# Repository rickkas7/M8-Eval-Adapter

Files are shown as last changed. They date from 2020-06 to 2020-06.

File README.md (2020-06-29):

# M8-Eval-Adapter

**Hardware design to facilitate prototyping Tracker One designs on the Tracker SoM Evaluation Board**

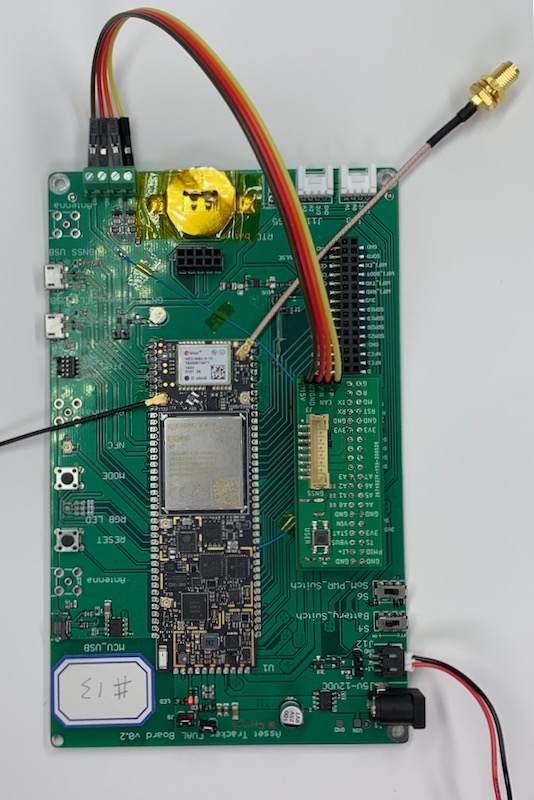
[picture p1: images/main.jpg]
Main Image


This is a simple board you can assemble that makes it easier to prototype designs that will eventually use the Tracker One or Tracker SoM Carrier Board, using the Tracker SoM Evaluation Board.

It fits on the 40 pin expansion connector on the Tracker SoM Evaluation Board and includes features that are on the Tracker One and Tracker Carrier Board:

- B8B-PH connector on the board, the same connector as on the Tracker Carrier Board
- Thermistor (temperature sensor) connected to A0.
- USER button connected to A1
- Blue GNSS LED connected to A2
- CAN connection

The CAN connection is necessary because CAN is not exposed on the 40-pin header. Short wires connect to the screw terminals on the Tracker SoM evaluation board so the CAN will be available on the M8 connector.

**Note:** The Tracker One supports up to 30V on the M8 connector. This adapter board does not have the same power supply as the Tracker One and Tracker Carrier Board. **This adapter board only supports up to 12V using the B8B-PH as a power input!** 

## About the M8 and B8B-PH Connector

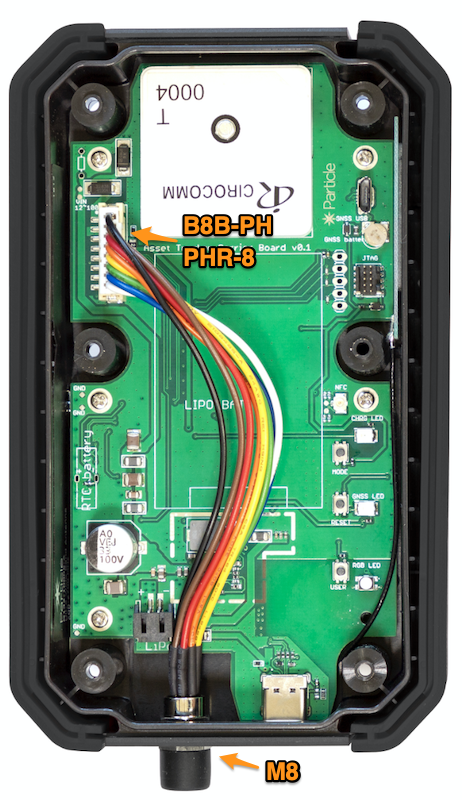
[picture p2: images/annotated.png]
Diagram of inside cable


The Tracker Carrier Board in the Tracker One has a B8B-PH connector on the board.

The Tracker One has a small cable with a PHR-8 connector (fits into the B8B-PH) on one end and an M8 8-pin male IP67 on the other. The M8 end fits into a hole in the case. This is the cable inside the Tracker One:

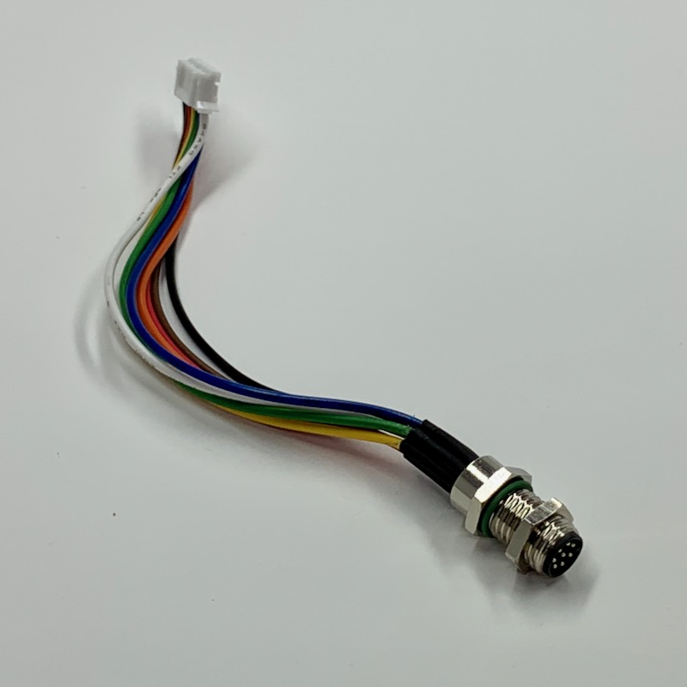
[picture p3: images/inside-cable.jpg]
Cable inside Tracker One


Your Tracker One project will typically use a M8 8-pin female cable. Here's one that has wires on the other end.

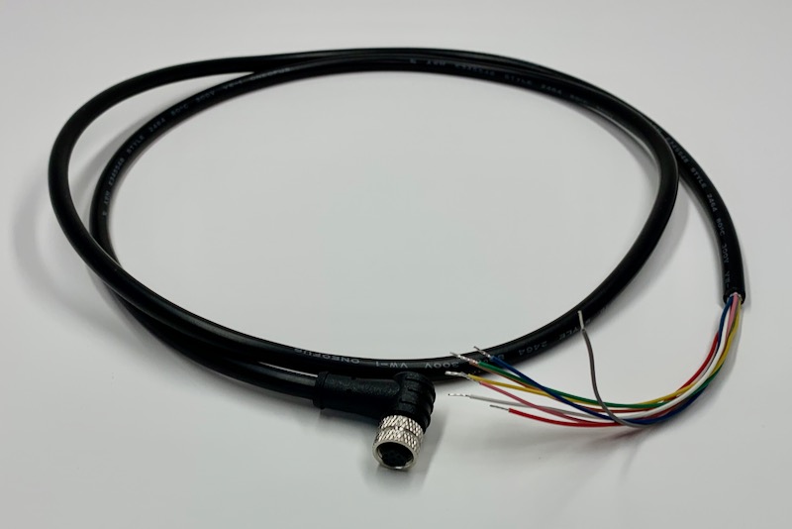
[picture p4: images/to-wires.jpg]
M8 to Wires


You'd typically connect those wires to your custom expansion board using one of several methods:

- Terminate with pins in a PHR-8 to mate with a B8B-PH on your expansion board
- Terminate with screw terminals on your board
- Terminate by soldering the wires to your board

For prototyping, you can just skip the M8 cable and use PHR-8 to wires, or a PHR-8 to PHR-8 cable, as in this example:

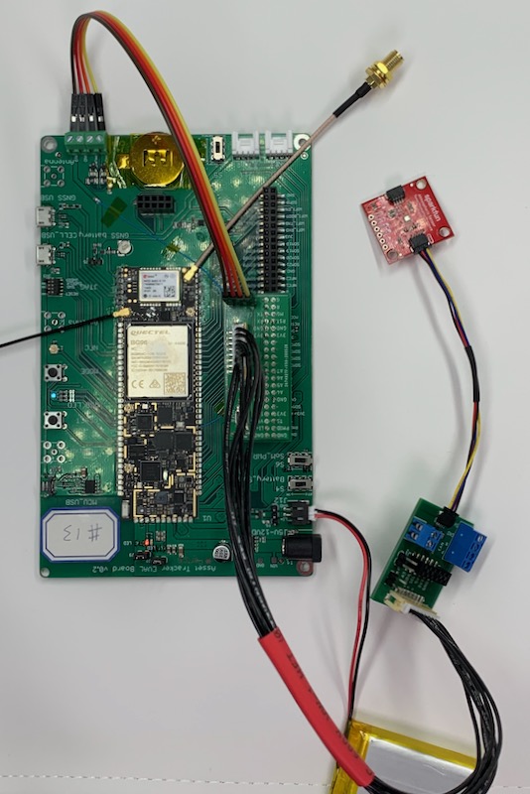
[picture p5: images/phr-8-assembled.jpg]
PHR-8


## Design

### Schematic

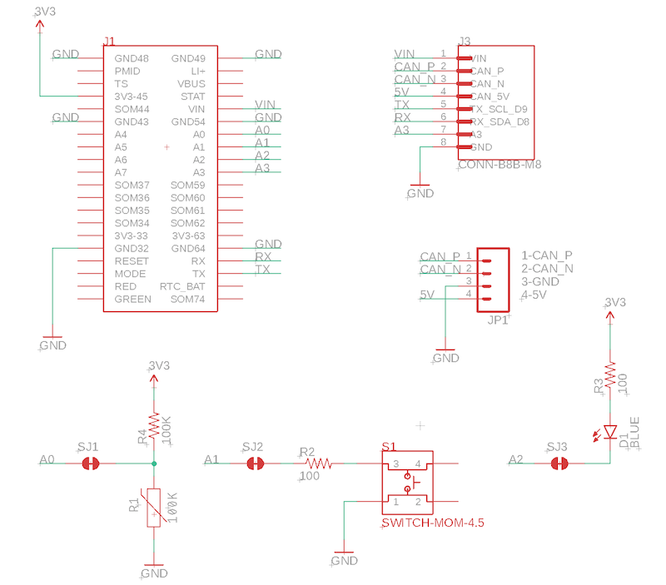
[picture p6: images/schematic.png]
Schematic


### Board

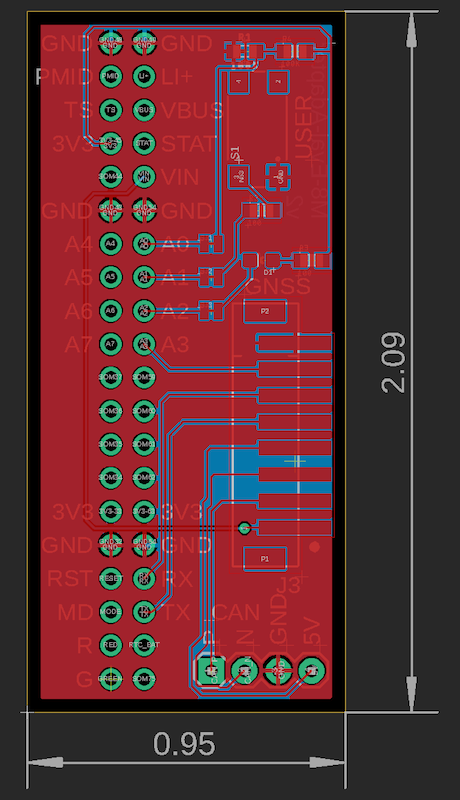
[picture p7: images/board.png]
Board


The Eagle CAD files (.sch and .brd) are in the [Github repository](https://github.com/rickkas7/M8-Eval-Adapter), along with the Gerber files.

## BoM (Bill of Materials)

| Quan | Part | Example | Price | 
| :---: | --- | --- | ---: |
| 1 | 100K NTC Thermistor | [Panasonic ERT-J1VR104FM](https://www.digikey.com/product-detail/en/panasonic-electronic-components/ERT-J1VR104FM/P122067CT-ND/7069667) | $0.39 |
| 2 | 100 ohm resistor 0603 | [Panasonic ERJ-3GEYJ101V](https://www.digikey.com/product-detail/en/panasonic-electronic-components/ERJ-3GEYJ101V/P100GCT-ND/134714) | | 
| 1 | 100K resistor 0603 | [Panasonic ERJ-3EKF1003V](https://www.digikey.com/product-detail/en/panasonic-electronic-components/ERJ-3EKF1003V/P100KHCT-ND/198110) | | 
| 1 | Blue LED 0603 | [Lite-On LTST-C193TBKT-5A](https://www.digikey.com/product-detail/en/lite-on-inc/LTST-C193TBKT-5A/160-1827-1-ND/2355044) | $0.47 |
| 1 | 4.5mm momentary switch | [E Switch TL3305AF160QG](https://www.digikey.com/product-detail/en/e-switch/TL3305AF160QG/EG5350CT-ND/5816195) | $0.20 |
| 1 | B8B-PH Connector | [JST B8B-PH-SM4-TB(LF)(SN)](https://www.digikey.com/product-detail/en/jst-sales-america-inc/B8B-PH-SM4-TB-LF-SN/455-1740-1-ND/926837) | $1.00 |
| | Male header pins 0.1" | [Sullins PRPC040SAAN-RC](https://www.digikey.com/product-detail/en/PRPC040SAAN-RC/S1011EC-40-ND/2775214) | | 

## Assembly Diagram

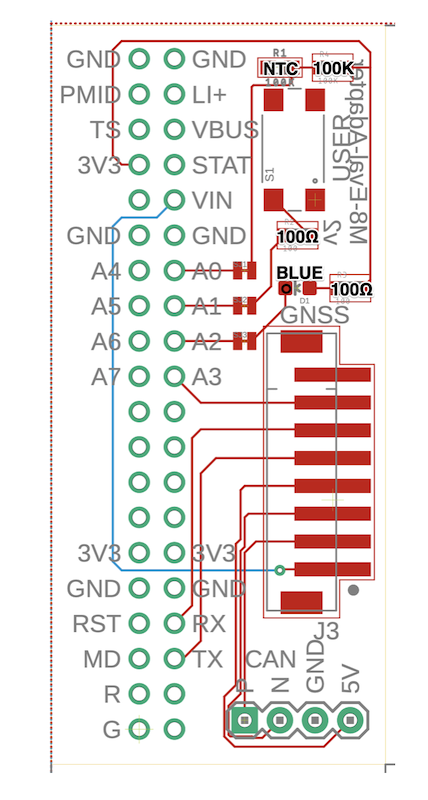
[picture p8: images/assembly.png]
Assembly


## Enabling Firmware Features

To enable these features in the Tracker Edge firmware, edit tracker_config.h and make sure these are defined. They default to not being defined on the Tracker SoM Evaluation board.

```
#define TRACKER_THERMISTOR                    (A0)
#define TRACKER_USER_BUTTON                   (A1)
#define TRACKER_GNSS_LOCK_LED                 (A2)
```

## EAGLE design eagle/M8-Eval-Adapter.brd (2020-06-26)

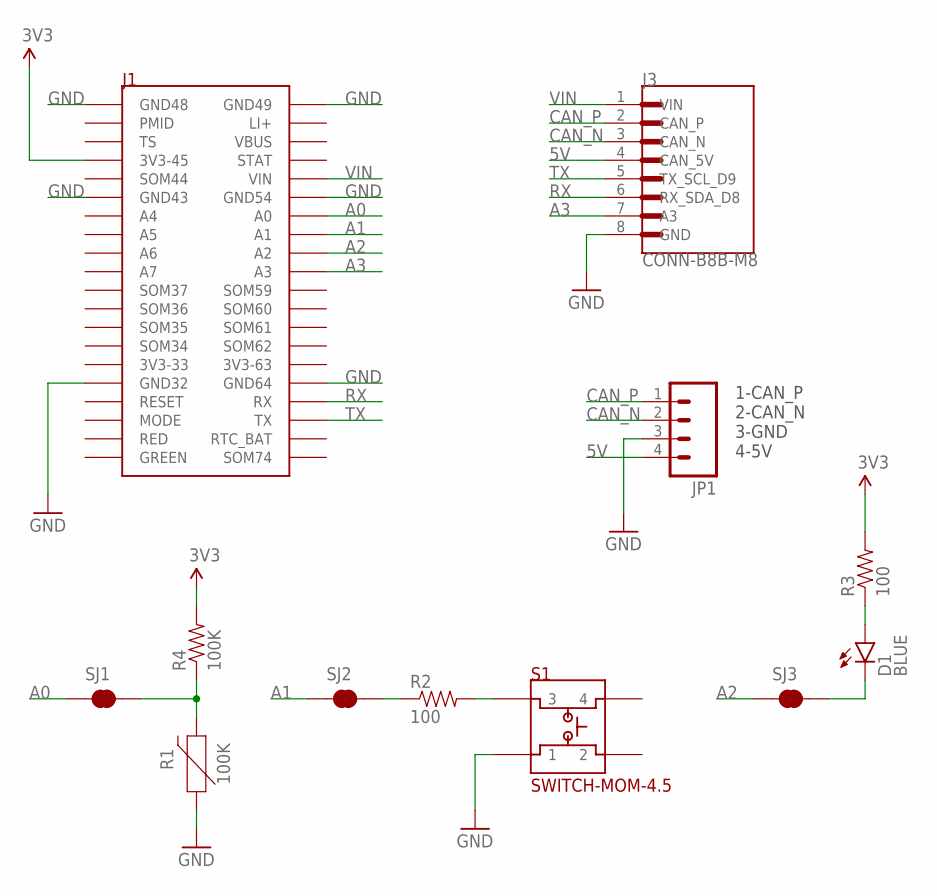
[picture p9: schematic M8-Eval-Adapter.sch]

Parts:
D1: BLUE; LED-0603
J1: HDR-TRACKER-EVAL-MAIN
J3: CONN-B8B-M8; JST_B8B-PH-SM4-TB(LF)(SN)
JP1: M04PTH; 1X04
R1: 100K; 0603
R2, R3: 100; 0603-RES
R4: 100K; 0603-RES
S1: SWITCH-MOM-4.5
SJ1, SJ2, SJ3: JUMPER-PAD-2-NC_BY_TRACENO_SILK; PAD-JUMPER-2-NC_BY_TRACE_NO_SILK

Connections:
3V3: J1.3V3-45, R3.2, R4.2
5V: J3.4 (CAN_5V), JP1.4
A0: J1.A0, SJ1.1
A1: J1.A1, SJ2.1
A2: J1.A2, SJ3.1
A3: J1.A3, J3.7 (A3)
CAN_N: J3.3 (CAN_N), JP1.2
CAN_P: J3.2 (CAN_P), JP1.1
GND: J1.GND32, J1.GND43, J1.GND48, J1.GND49, J1.GND54, J1.GND64, J3.8 (GND), JP1.3, R1.1, S1.1
unnamed: R2.1, SJ2.2
unnamed: R1.2, R4.1, SJ1.2
unnamed: R2.2, S1.3
unnamed: D1.C, SJ3.2
unnamed: D1.A, R3.1
RX: J1.RX, J3.6 (RX_SDA_D8)
TX: J1.TX, J3.5 (TX_SCL_D9)
VIN: J1.VIN, J3.1 (VIN)

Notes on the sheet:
1-CAN_P 2-CAN_N 3-GND 4-5V

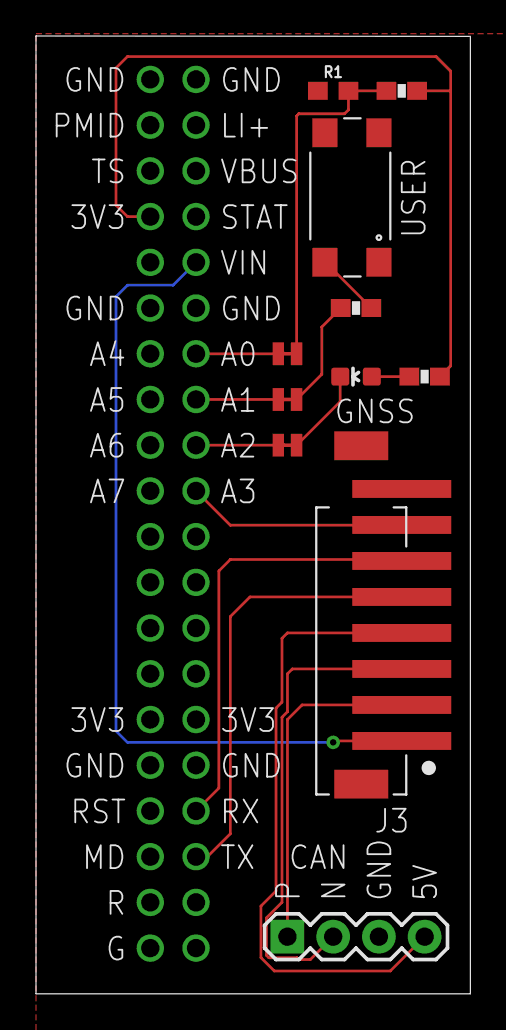
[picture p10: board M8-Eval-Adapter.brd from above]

Board: 2 copper layers, 24.1 x 53.2 mm, 12 parts (0 on the bottom side), 17 nets.

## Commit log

2020-06-26 Initial checkin
    [M8-Eval-Adapter.brd, M8-Eval-Adapter.sch]
2020-06-26 Add power supply note
